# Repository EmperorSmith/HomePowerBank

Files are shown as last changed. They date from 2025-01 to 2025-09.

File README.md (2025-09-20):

# HomePowerBank

This project is a combined hardware-software effort around designing a control / management system for a home power bank. Unlike commercial USB power banks, this one is intended to serve as a sort of "generator substitute," having a stack of batteries large enough to supply an inverter during situations that otherwise lack power (general outage, off-grid living, etc).

# Design Goals

## Primary Goals

- Monitor a multi-cell battery stack
    - Measure cell voltage
    - Measure stack voltage
    - Measure stack current
    - Measure temperatures
    - Estimate cell state-of-charge
- Report monitored state to user
- Accept and react to user input for basic operations
- Protect pack against fault conditions
    - Overvoltage / Overcharge
    - Undervoltage / Undercharge
    - Overcurrent
    - Overtemperature
- Integrate control of external charger and inverter
    - Connect & disconnect battery stack bus and external devices
    - Produce on/off control output to charger
    - Take in fault input from charger
    - Produce on/off control output to inverter
    - Take in fault input from inverter

## Secondary Goals

- Provide bidirectional USB-C charging port
    - Supply external loads with 5V 1.5A power
    - Trickle-charge bank from external supply
- Take control commands from external communication interface
- Implement advanced diagnostics
- Implement flexible / extensible stack architecture
    - Adapt to different cell and IC counts
    - Adapt to different cell chemistries

# Tools

As much as possible, the tools used to produce the design should be freely available.

- Circuit schematic and layout creation will take place in [KiCAD](www.kicad.org)
- Block diagrams and similar drawing should use [draw.io](www.diagrams.net)
- Circuit simulations should be conducted in a free SPICE tool, like [ngspice](https://ngspice.sourceforge.io/) or [LTSpice](https://www.analog.com/en/resources/design-tools-and-calculators/ltspice-simulator.html)
- Documentation should be created using the Markdown language / format

# Philosophy

## System Design

When in doubt, design should err on the side of over-engineering, especially for the prototype phase.

## Project Code of Conduct

"Be excellent to each other" *- Bill S. Preston, Esq.*

## Usability

The system in basic form should be fully usable from the standpoint of a non-engineer, but should also offer the capabilities for a knowledgeable person to modify / alter the system to their desires.

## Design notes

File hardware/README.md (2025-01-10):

# System Blocks

## Internal Power Supply

### Description

This system will take the battery bank voltage and convert it to 5V to supply various aspects of the system (microcontroller, USB port, maybe even the BMS chips).

With the battery bank currently targeted at a 16S LFP configuration, this limits the maximum voltage to about 55V. Conventional buck regulators should be able to convert at this ratio and voltage range. It is also permissible to use a flyback regulator, although this will present additional challenges over a buck regulator.

If other system rails are needed, secondary voltage regulators will be added.

There will be a secondary LV battery backup system to ensure that faults with the main bank will not cause immediate shutdown of the system. This is to ensure good shutdown and startup behavior and preserve information about the system.

### Requirements

- Input Voltage : 32V to 56V
- Input Current : (as needed)
- Output Voltage : 5V +/- 0.2V
- Output Current : at least 1.5A, no more than 3A

## Trickle Charge Circuit

### Description

This system will take in 5V from the USB port and boost it up to about 55V to trickle-charge the battery bank.

The power conversion topology chosen is a flyback converter. The step-up ratio is just too large to use a conventional boost converter.

Ideally, the output of the buck regulator will have a constant-current-limiting circuit attached to it to accommodate a wide range of battery bank voltages.

### Requirements

- Input Voltage : 5.0V +/- 0.25V
- Input Current : no more than 1A average
- Output Voltage : 53V +/- 2V
- Output Current : no more than 50mA

## USB Interface

### Description

A USB C socket will be present on the unit. It will be capable of both supplying power to an external load and drawing power from an external source.

### Requirements

Despite having a USB C connector, the port will not have full USB 3 communication capabilities. If communication is added, it will be USB 2.x compliant only.

While the port will be able to both source and sink power, USB PD communication will not be implemented. Instead, a user-activated switch will determine the direction of the power flow. On switch toggle, the USB port will fully disconnect, then reconfigure the CC pins as necessary and monitor for connection.

When sourcing power, the interface will use CC pin resistor strapping to communicate the availability of up to 1.5A of current at 5.0V to downstream devices.

When sinking power, the interface will measure the CC pin voltage and respect the current limits communicated in that manner. The trickle charge circuit will not activate unless at least 1.5A of current is available from the upstream device.

The USB port will include a power switch and current sense amplifier to monitor operation. Fault conditions will trigger a port shutdown. Reconnection will be attempted after a timeout.

## Microcontroller

### Description

A local microcontroller will handle all operation and monitoring of the battery bank and attached systems (charger, inverter, USB-attached device). It will interface with users only in the most basic of manners (buttons / switches / LED indicators). More complex interactions will require an external device, to which the microcontroller will provide information for futher processing and display. The microcontroller will retain key state information across power cycles.

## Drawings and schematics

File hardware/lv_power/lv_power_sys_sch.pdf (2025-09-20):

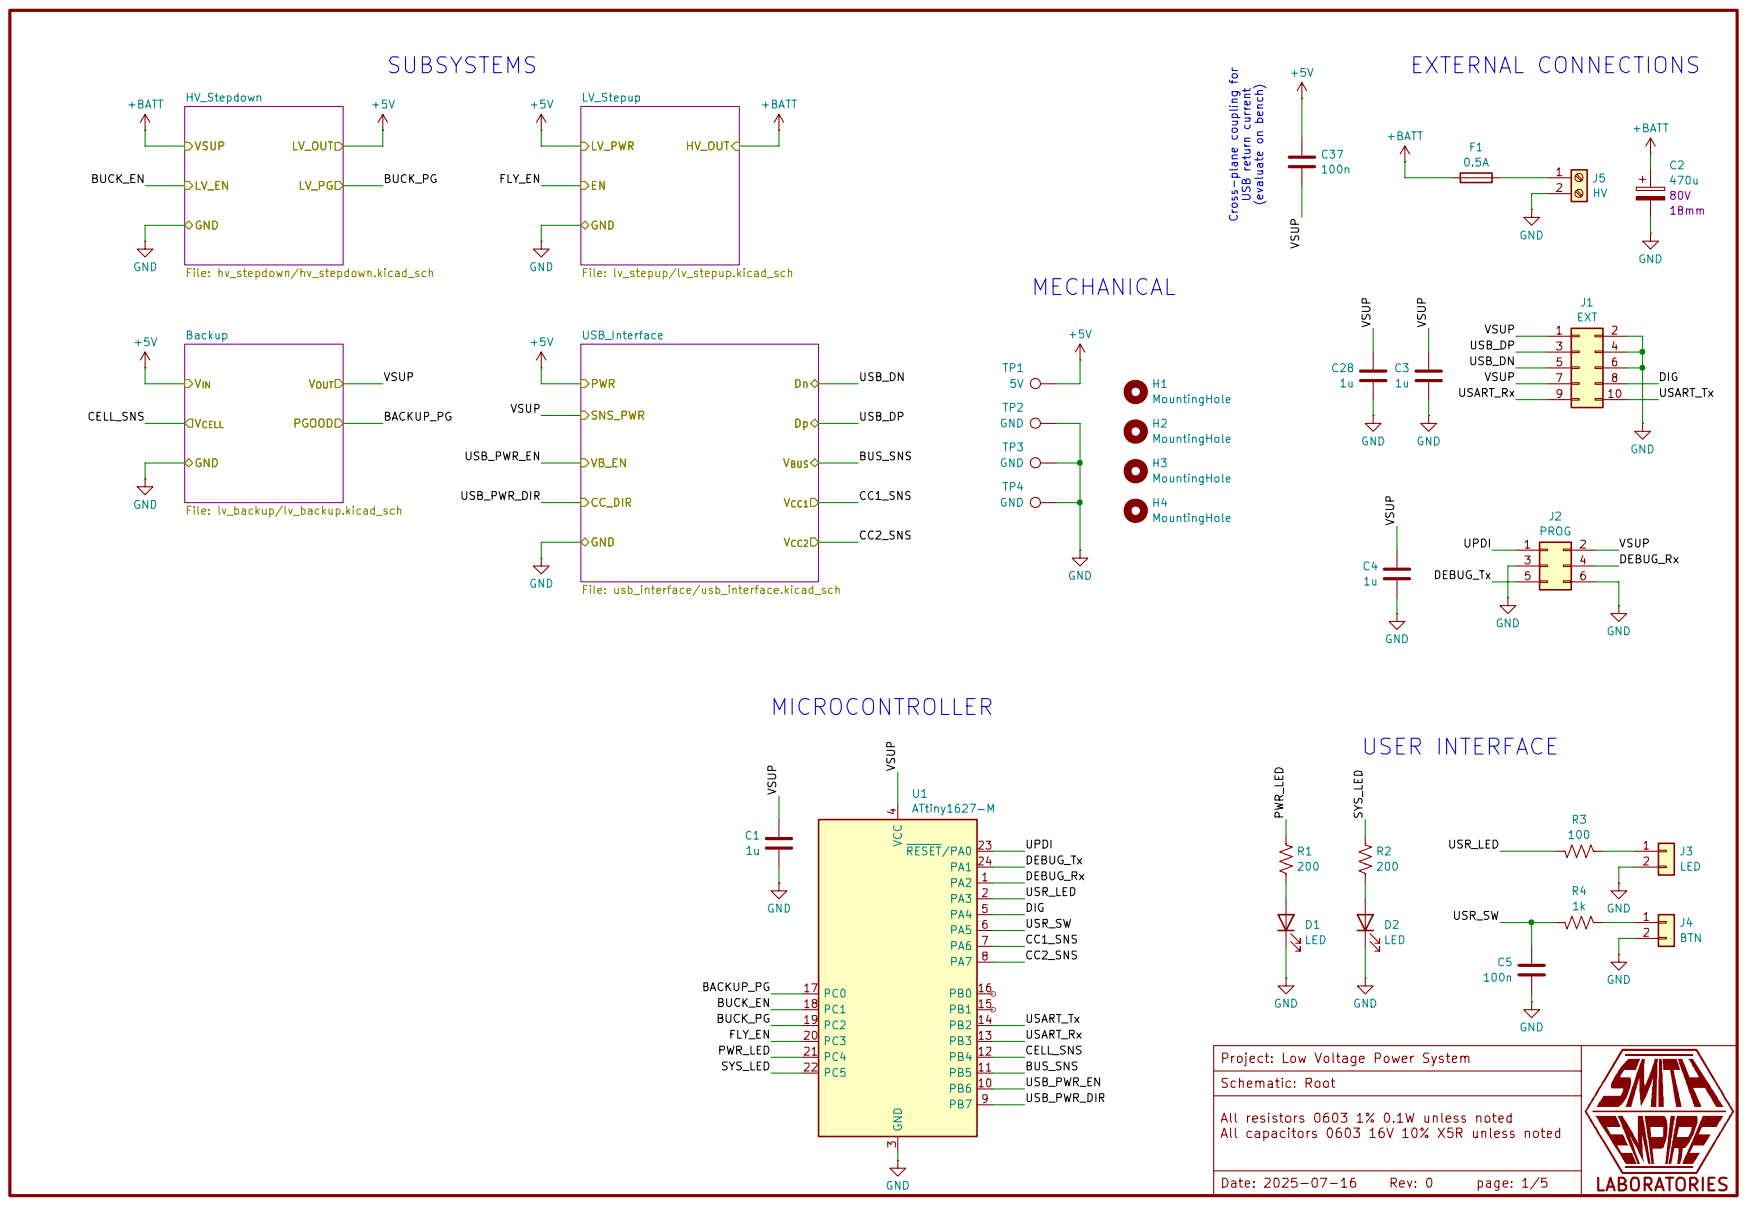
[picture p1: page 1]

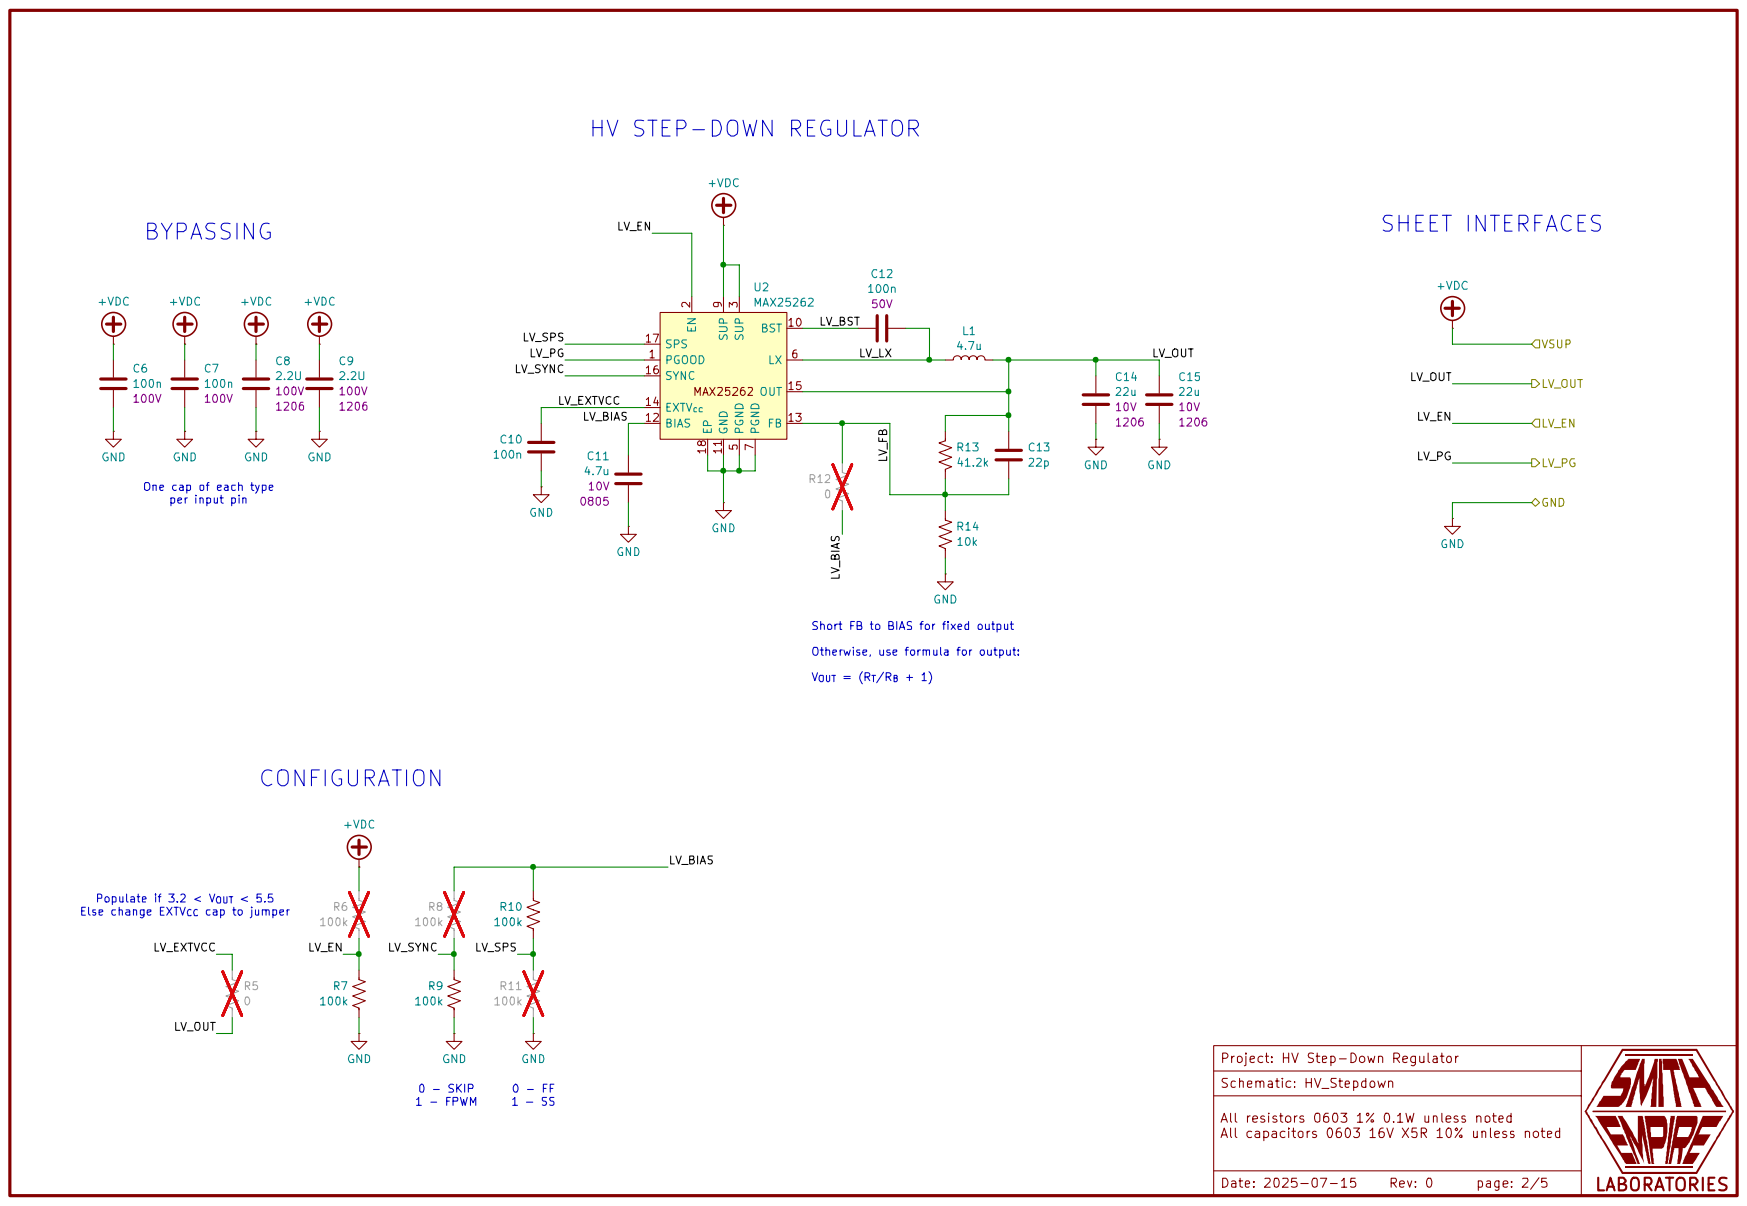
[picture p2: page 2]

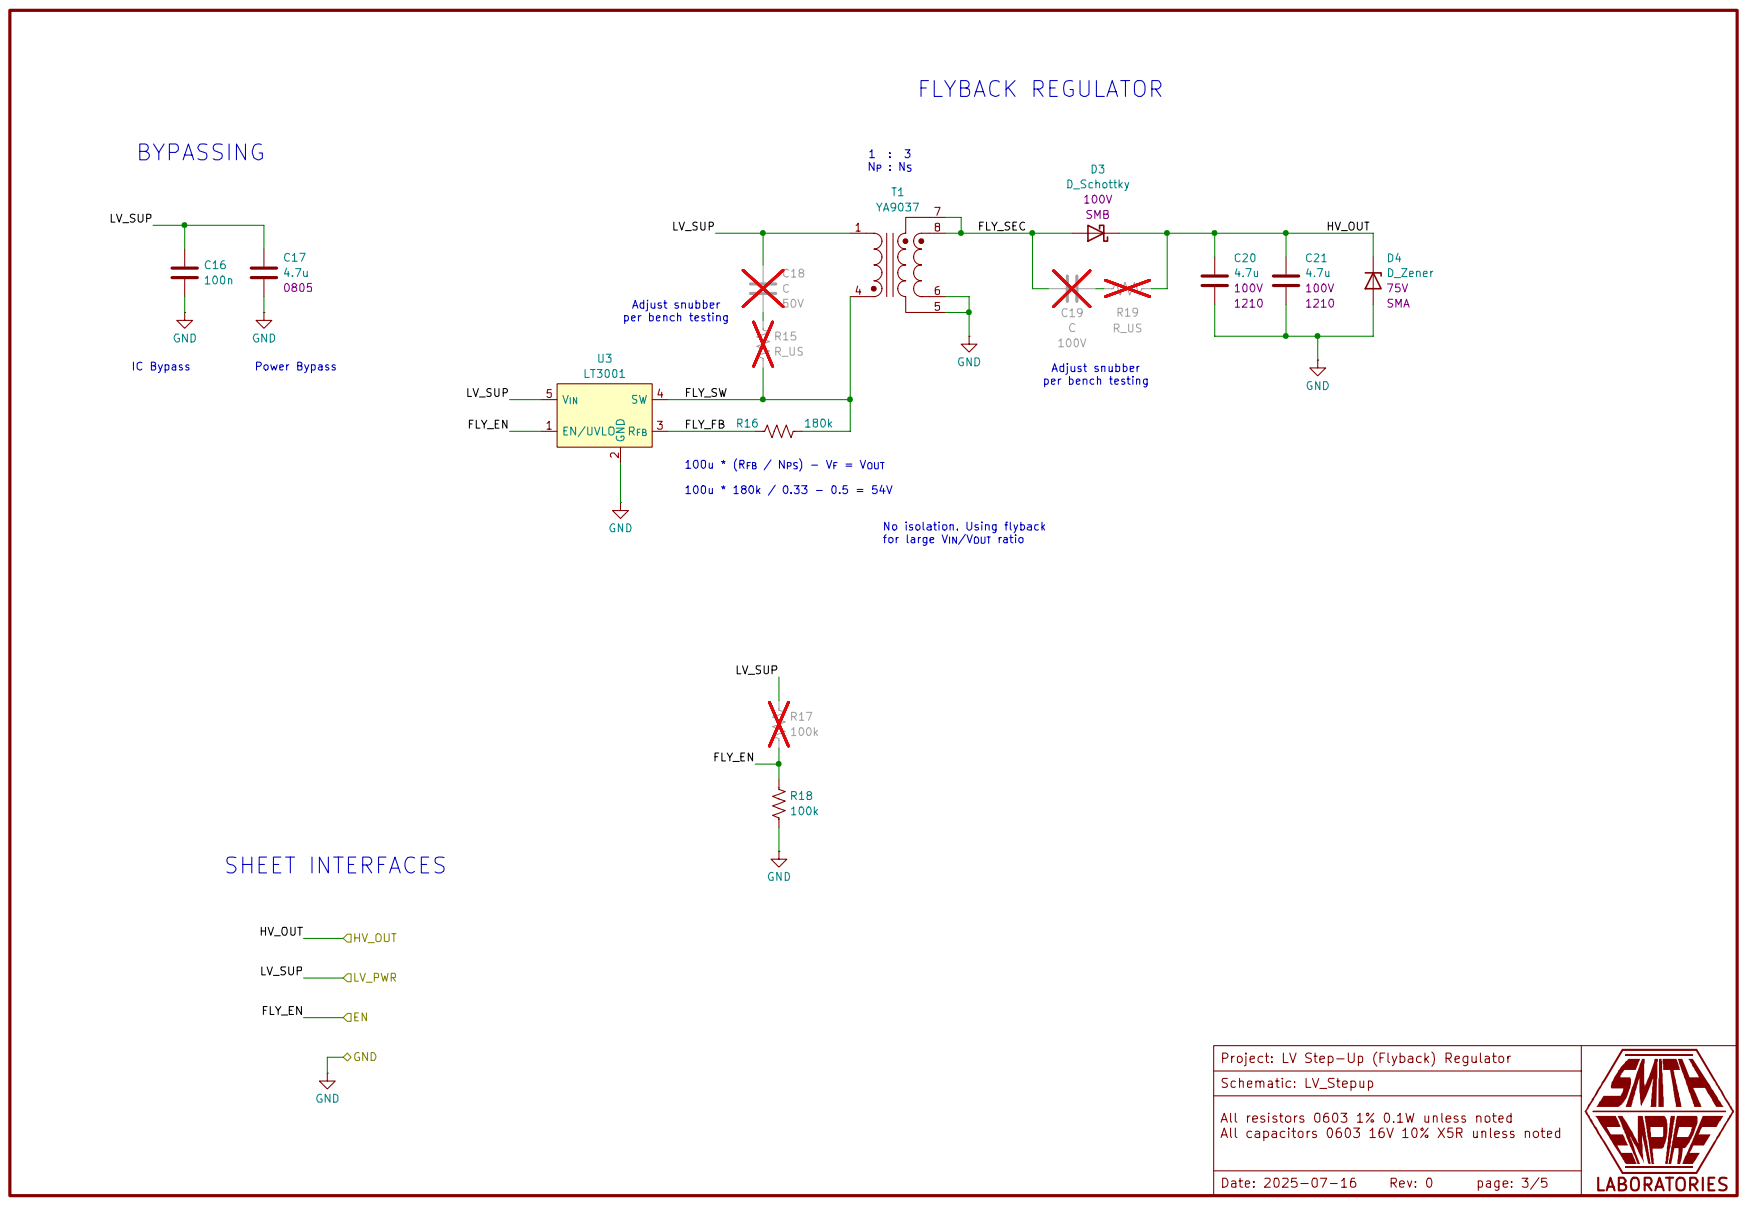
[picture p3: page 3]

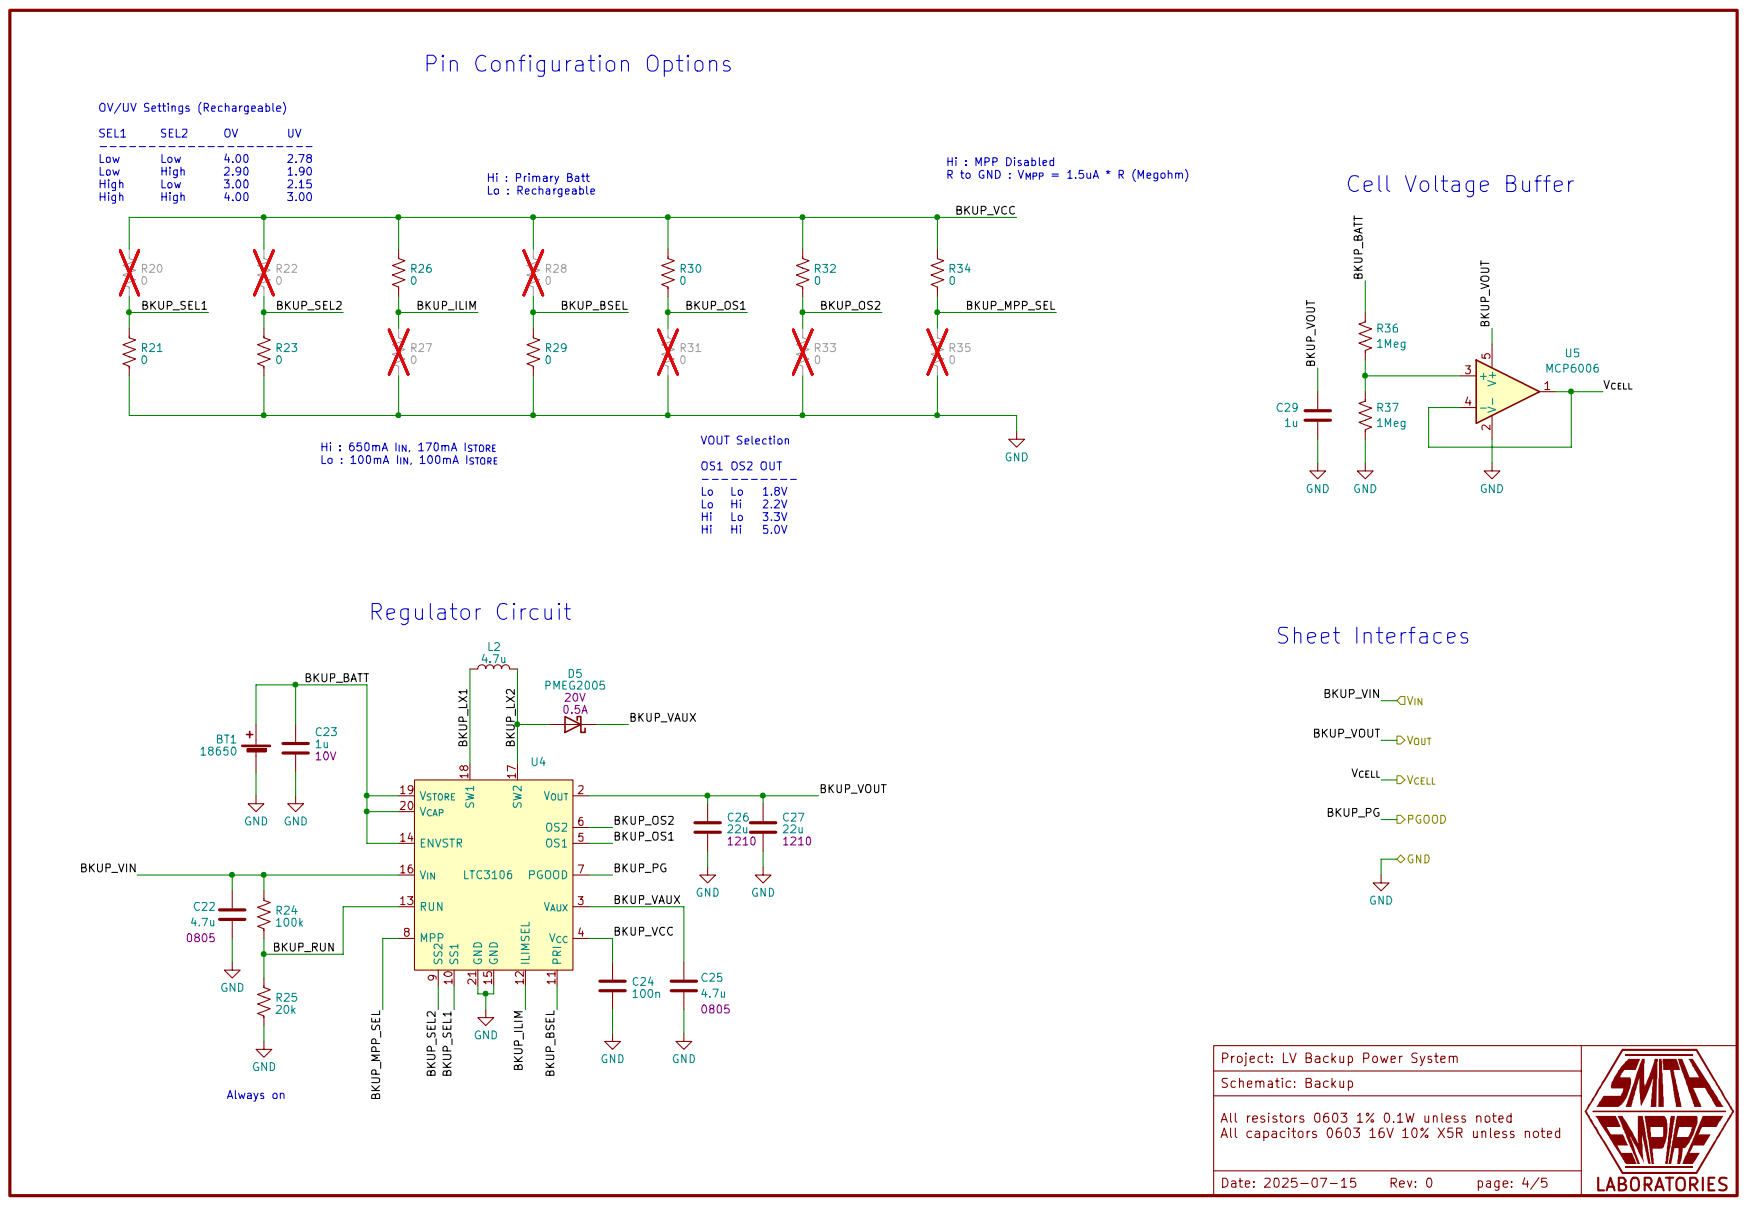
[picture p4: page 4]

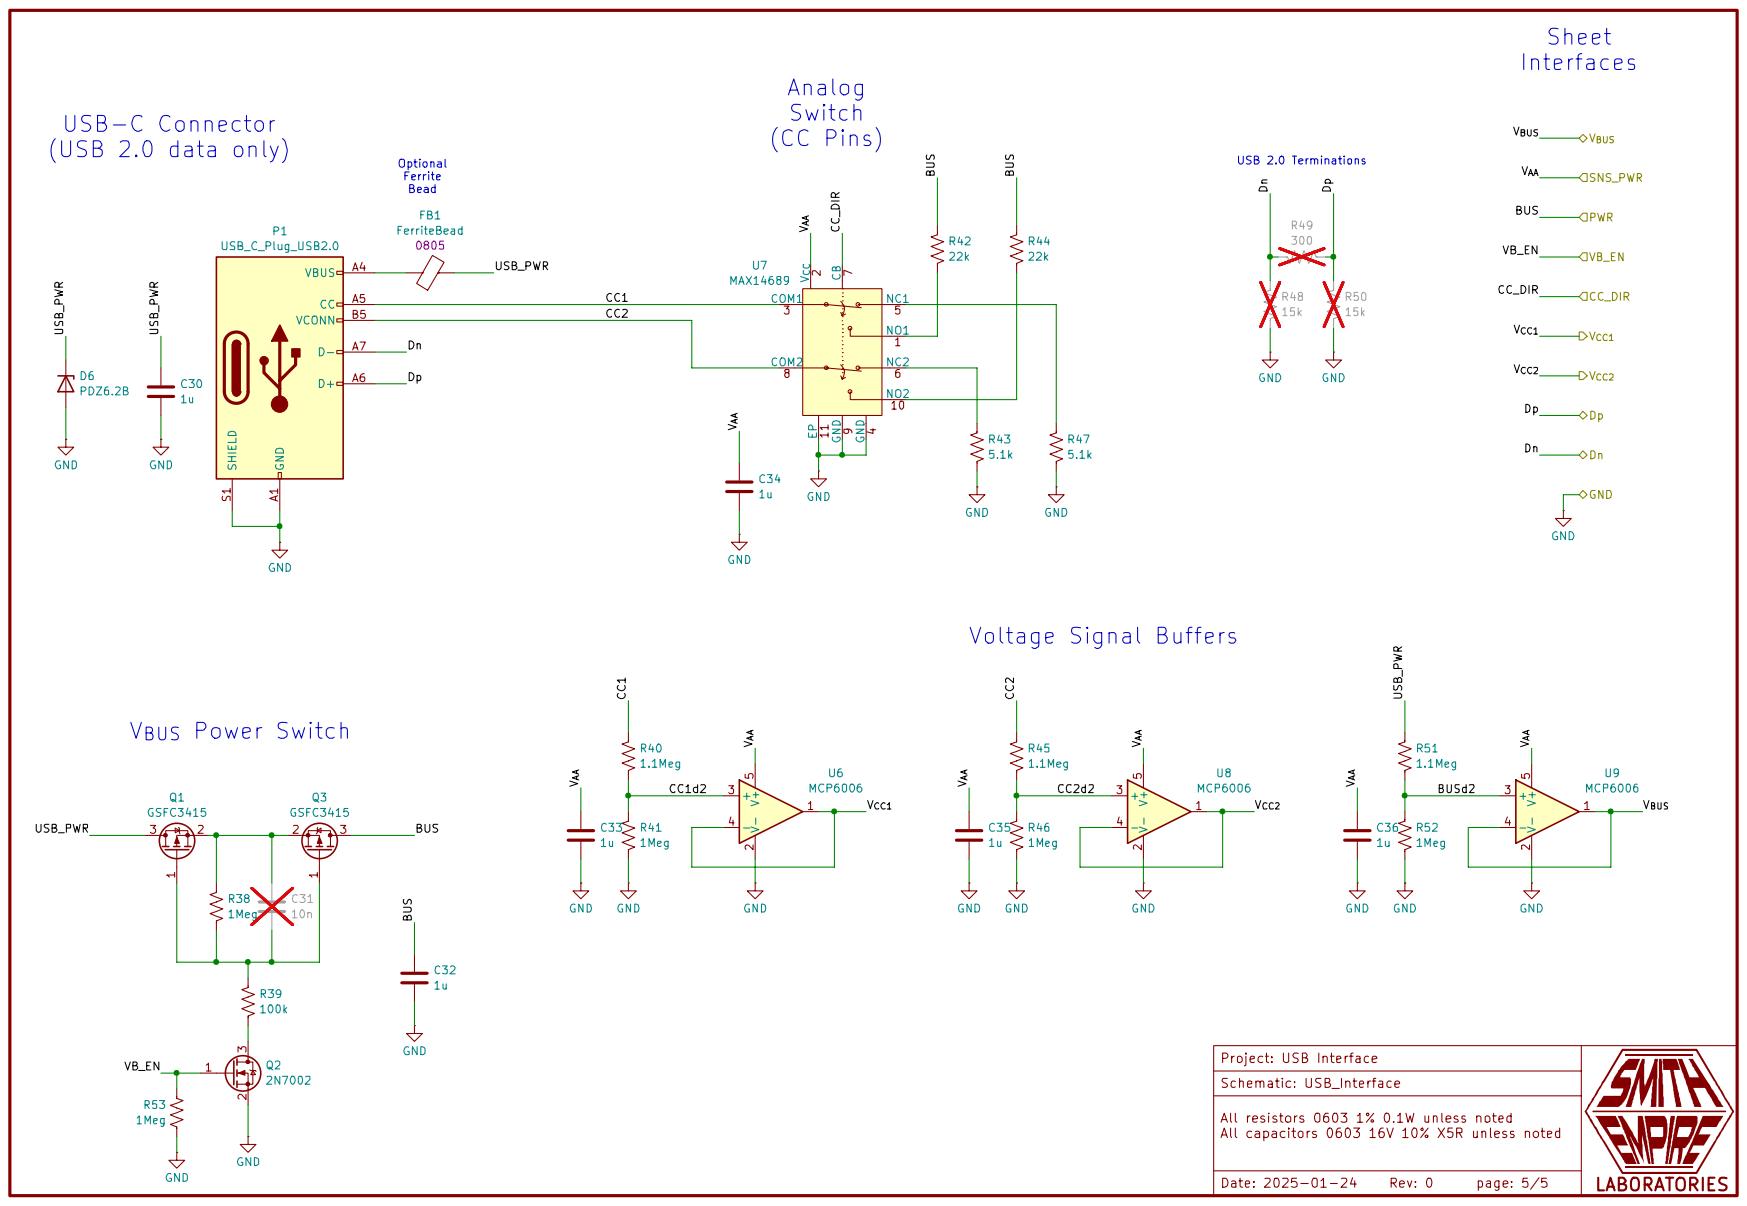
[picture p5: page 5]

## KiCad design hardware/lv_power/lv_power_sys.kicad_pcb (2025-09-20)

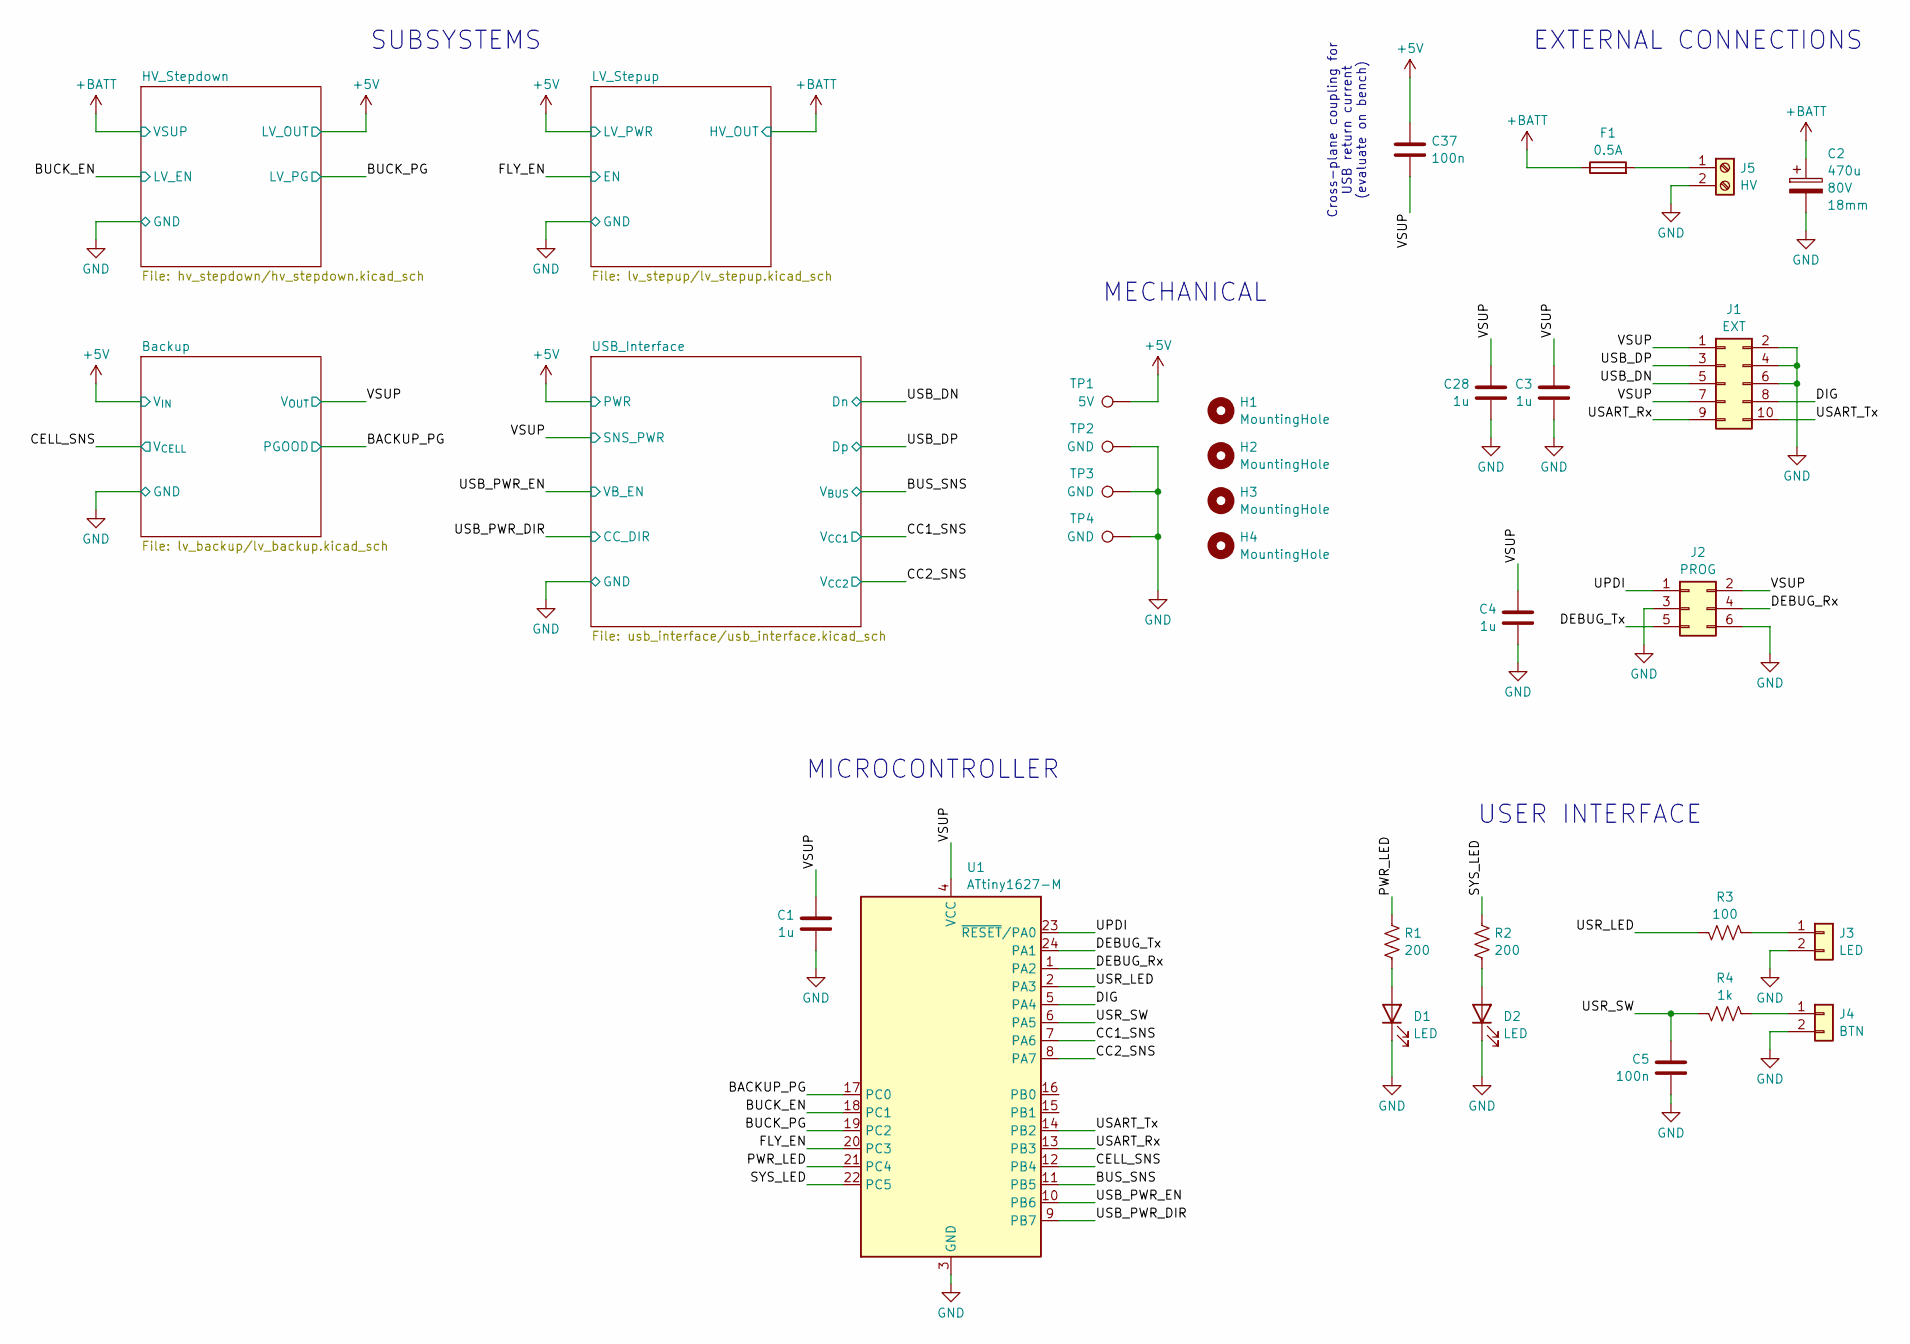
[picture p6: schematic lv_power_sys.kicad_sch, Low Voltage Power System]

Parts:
C1, C3, C4, C28: 1u; C_0603_1608Metric
C2: 470u; CP_Elec_18x17.5
C5, C37: 100n; C_0603_1608Metric
D1, D2: LED; D_0603_1608Metric
F1: 0.5A; Fuseholder_Clip-5x20mm_Keystone_3512_Inline_P23.62x7.27mm_D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
H1, H2, H3, H4: MountingHole; MountingHole_3.2mm_M3
J1: EXT; IDC-Header_2x05_P2.54mm_Vertical
J2: PROG; PinHeader_2x03_P2.54mm_Vertical
J3: LED; PinHeader_1x02_P2.54mm_Vertical
J4: BTN; PinHeader_1x02_P2.54mm_Vertical
J5: HV; SolderWire-0.15sqmm_1x02_P4mm_D0.5mm_OD1.5mm
R1, R2: 200; R_0603_1608Metric
R3: 100; R_0603_1608Metric
R4: 1k; R_0603_1608Metric
TP1: 5V; TestPoint_Pad_D1.5mm
TP2, TP3, TP4: GND; TestPoint_Pad_D1.5mm
U1: ATtiny1627-M; QFN-24-1EP_4x4mm_P0.5mm_EP2.6x2.6mm

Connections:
+5V: C37.1, TP1.1; also elsewhere on the board
+BATT: C2.1, F1.1; also elsewhere on the board
/BACKUP_PG: U1.17 (PC0); also elsewhere on the board
/BUCK_EN: U1.18 (PC1); also elsewhere on the board
/BUCK_PG: U1.19 (PC2); also elsewhere on the board
/BUS_SNS: U1.11 (PB5); also elsewhere on the board
/CC1_SNS: U1.7 (PA6); also elsewhere on the board
/CC2_SNS: U1.8 (PA7); also elsewhere on the board
/CELL_SNS: U1.12 (PB4); also elsewhere on the board
/DEBUG_Rx: J2.4, U1.1 (PA2)
/DEBUG_Tx: J2.5, U1.24 (PA1)
/DIG: J1.8, U1.5 (PA4)
/FLY_EN: U1.20 (PC3); also elsewhere on the board
/LED0: R1.2, U1.21 (PC4)
/LED1: R2.2, U1.22 (PC5)
/UPDI: J2.1, U1.23 (~RESET/PA0)
/USART_Rx: J1.9, U1.13 (PB3)
/USART_Tx: J1.10, U1.14 (PB2)
/USB_DN: J1.5; also elsewhere on the board
/USB_DP: J1.3; also elsewhere on the board
/USB_PWR_DIR: U1.9 (PB7); also elsewhere on the board
/USB_PWR_EN: U1.10 (PB6); also elsewhere on the board
/USR_LED: R3.1, U1.2 (PA3)
/USR_SW: C5.1, R4.1, U1.6 (PA5)
/VSUP: C1.1, C3.1, C4.1, C28.1, C37.2, J1.1, J1.7, J2.2, U1.4 (VCC); also elsewhere on the board
GND: C1.2, C2.2, C3.2, C4.2, C5.2, C28.2, D1.1 (K), D2.1 (K), J1.2, J1.4, J1.6, J2.3, J2.6, J3.2, J4.2, J5.2, TP2.1, TP3.1, TP4.1, U1.3 (GND), U1.25 (GND); also elsewhere on the board
unnamed: D1.2 (A), R1.1
unnamed: D2.2 (A), R2.1
unnamed: J3.1, R3.2
unnamed: J4.1, R4.2
unnamed: F1.2, J5.1

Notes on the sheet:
USER INTERFACE
SUBSYSTEMS
EXTERNAL CONNECTIONS
Cross-plane coupling for USB return current (evaluate on bench)
MECHANICAL
MICROCONTROLLER

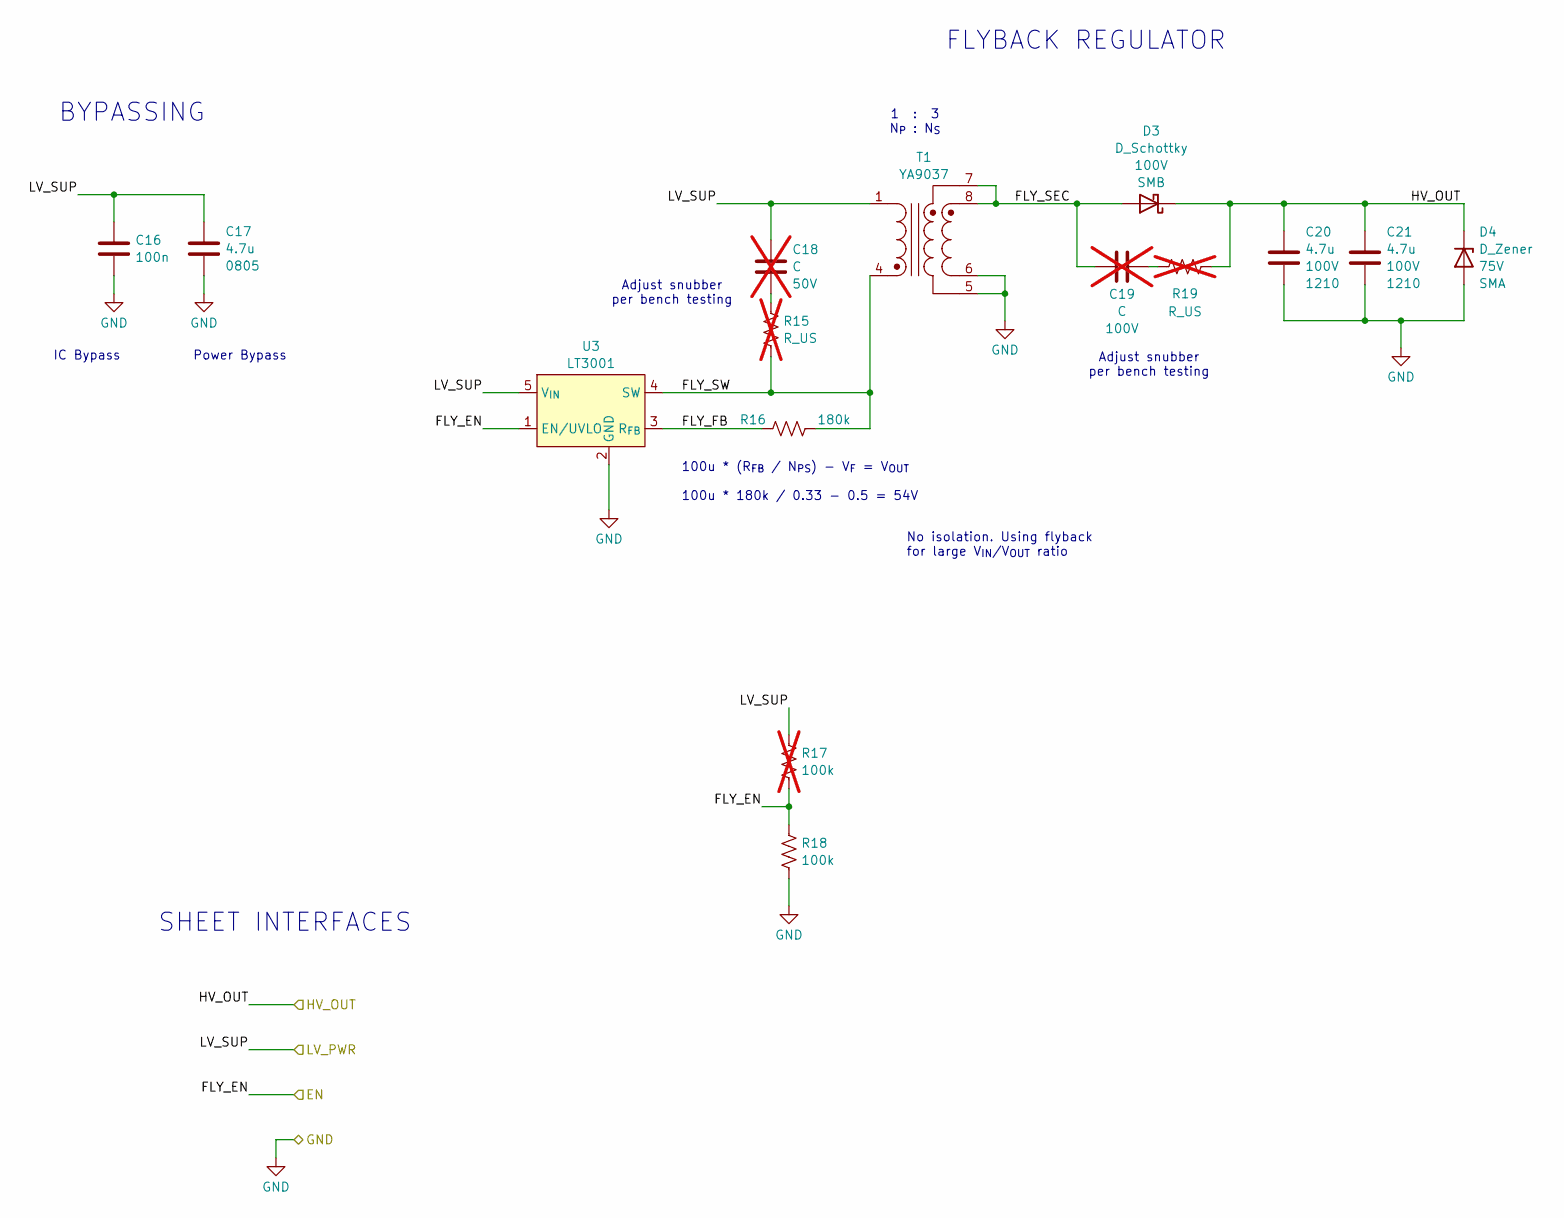
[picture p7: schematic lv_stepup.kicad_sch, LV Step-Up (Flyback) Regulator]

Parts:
C16: 100n; C_0603_1608Metric
C17: 4.7u; C_0805_2012Metric
C18, C19: C; C_0603_1608Metric; not fitted
C20, C21: 4.7u; C_1210_3225Metric
D3: D_Schottky; D_SMB
D4: D_Zener; D_SMA
R15, R19: R_US; R_0603_1608Metric; not fitted
R16: 180k; R_0603_1608Metric
R17: 100k; R_0603_1608Metric; not fitted
R18: 100k; R_0603_1608Metric
T1: YA9037; Coilcraft_YA903x
U3: LT3001; SOT-23-5

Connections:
+5V: C16.1, C17.1, C18.1, R17.2, T1.1, U3.5 (V_{IN}); also elsewhere on the board
+BATT: C20.1, C21.1, D3.1 (K), D4.1 (K), R19.2; also elsewhere on the board
/FLY_EN: R17.1, R18.2, U3.1 (EN/UVLO); also elsewhere on the board
/LV_Stepup/FLY_FB: R16.1, U3.3 (R_{FB})
/LV_Stepup/FLY_SEC: C19.1, D3.2 (A), T1.7, T1.8
/LV_Stepup/FLY_SW: R15.1, R16.2, T1.4, U3.4 (SW)
GND: C16.2, C17.2, C20.2, C21.2, D4.2 (A), R18.1, T1.5, T1.6, U3.2 (GND); also elsewhere on the board
unnamed: C18.2, R15.2
unnamed: C19.2, R19.1

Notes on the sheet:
No isolation. Using flyback for large V_{IN}/V_{OUT} ratio
IC Bypass
1 : 3 N_{P} : N_{S}
FLYBACK REGULATOR
100u * (R_{FB} / N_{PS}) - V_{F} = V_{OUT} 100u * 180k / 0.33 - 0.5 = 54V
SHEET INTERFACES
Adjust snubber per bench testing
Power Bypass
BYPASSING

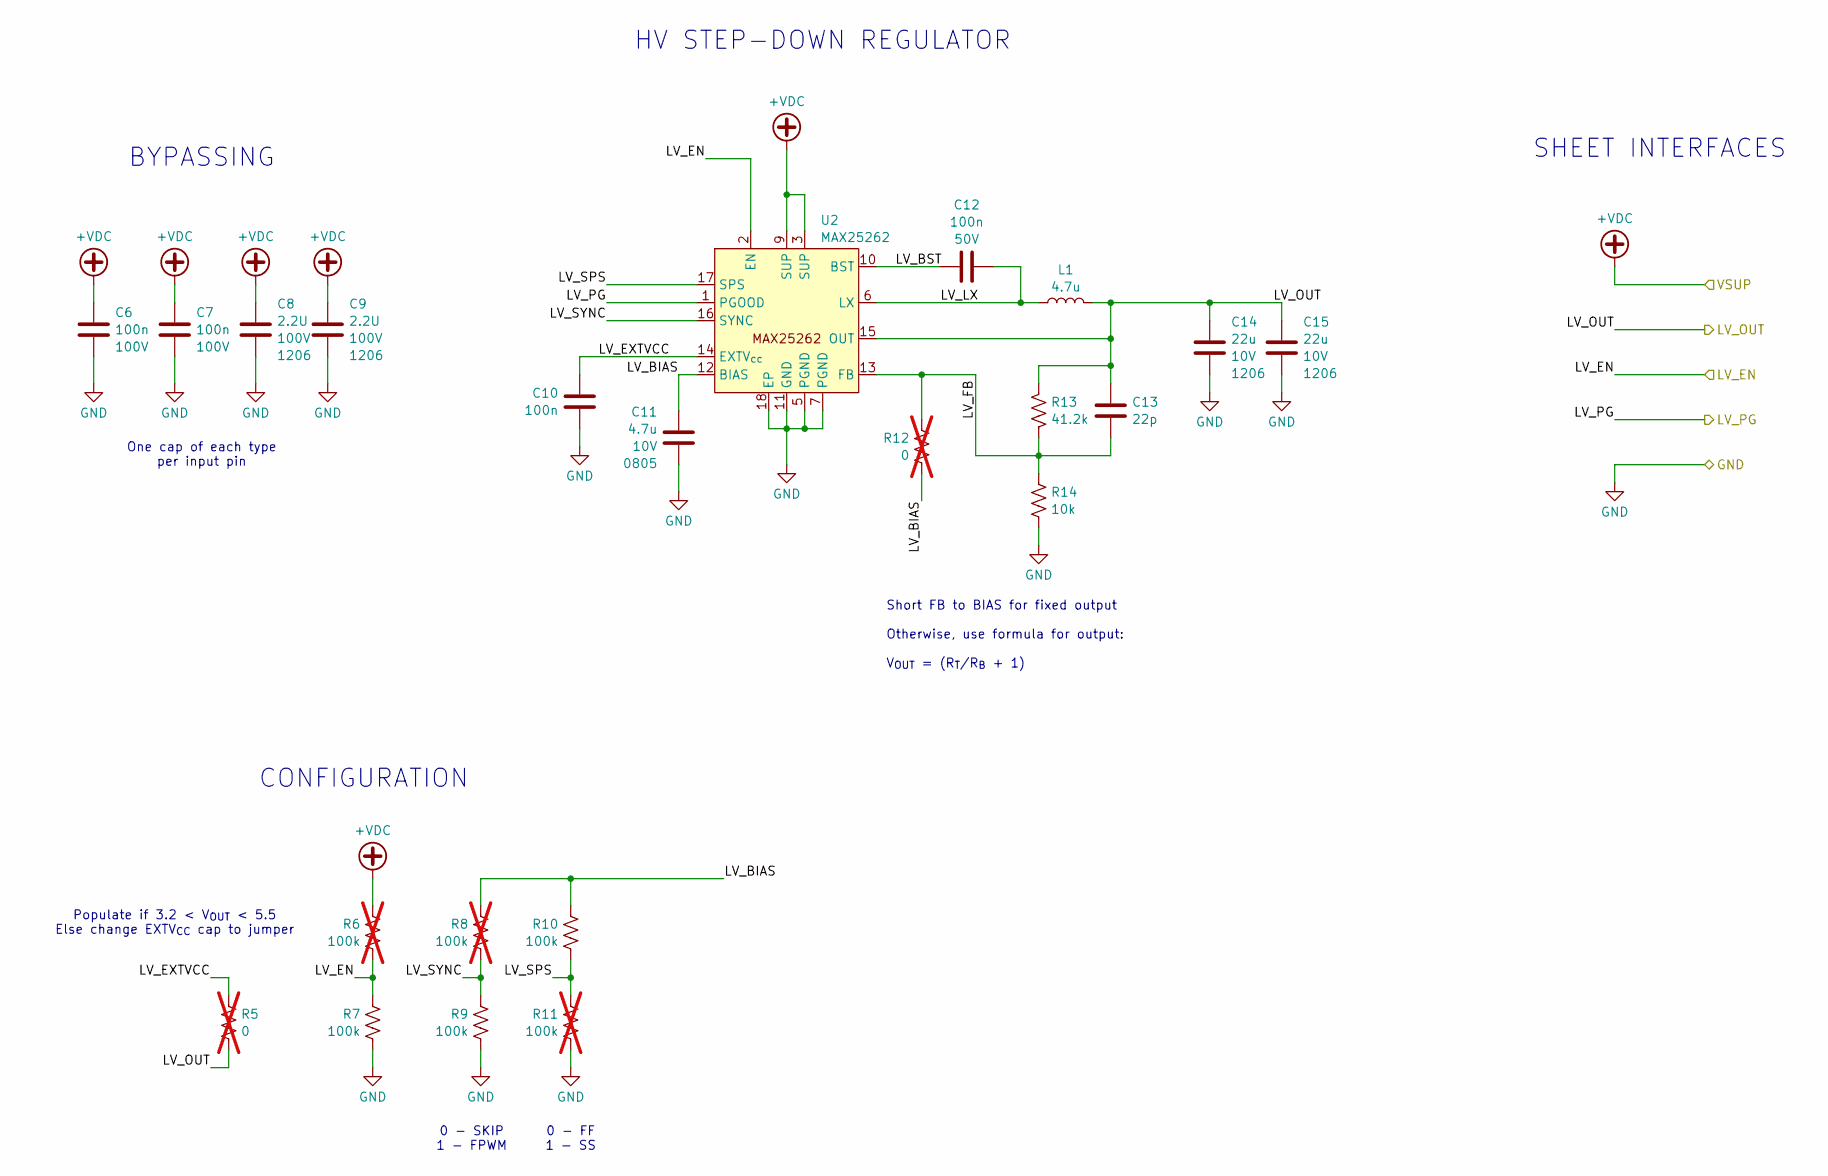
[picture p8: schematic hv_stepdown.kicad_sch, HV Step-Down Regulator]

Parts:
C6, C7, C10, C12: 100n; C_0603_1608Metric
C8, C9: 2.2U; C_1210_3225Metric
C11: 4.7u; C_0805_2012Metric
C13: 22p; C_0603_1608Metric
C14, C15: 22u; C_1210_3225Metric
L1: 4.7u; L_Coilcraft_XAL6060-XXX
R5, R12: 0; R_0603_1608Metric; not fitted
R6, R8, R11: 100k; R_0603_1608Metric; not fitted
R7, R9, R10: 100k; R_0603_1608Metric
R13: 41.2k; R_0603_1608Metric
R14: 10k; R_0603_1608Metric
U2: MAX25262; ADI_21-100429

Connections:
+5V: C13.2, C14.2, C15.2, L1.2, R5.1, R13.2, U2.15 (OUT); also elsewhere on the board
+BATT: C6.1, C7.1, C8.1, C9.1, R6.1, U2.3 (SUP), U2.9 (SUP); also elsewhere on the board
/BUCK_EN: R6.2, R7.1, U2.2 (EN); also elsewhere on the board
/BUCK_PG: U2.1 (PGOOD); also elsewhere on the board
/HV_Stepdown/LV_BIAS: C11.2, R8.1, R10.1, R12.2, U2.12 (BIAS)
/HV_Stepdown/LV_BST: C12.1, U2.10 (BST)
/HV_Stepdown/LV_EXTVCC: C10.1, R5.2, U2.14 (EXTV_{cc})
/HV_Stepdown/LV_FB: C13.1, R12.1, R13.1, R14.2, U2.13 (FB)
/HV_Stepdown/LV_LX: C12.2, L1.1, U2.6 (LX)
/HV_Stepdown/LV_SPS: R10.2, R11.1, U2.17 (SPS)
/HV_Stepdown/LV_SYNC: R8.2, R9.1, U2.16 (SYNC)
GND: C6.2, C7.2, C8.2, C9.2, C10.2, C11.1, C14.1, C15.1, R7.2, R9.2, R11.2, R14.1, U2.5 (PGND), U2.7 (PGND), U2.11 (GND), U2.18 (EP); also elsewhere on the board

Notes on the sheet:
HV STEP-DOWN REGULATOR
0 - SKIP 1 - FPWM
Populate if 3.2 < V_{OUT} < 5.5 Else change EXTV_{CC} cap to jumper
0 - FF 1 - SS
SHEET INTERFACES
Short FB to BIAS for fixed output Otherwise, use formula for output: V_{OUT} = (R_{T}/R_{B} + 1)
CONFIGURATION
BYPASSING
One cap of each type per input pin

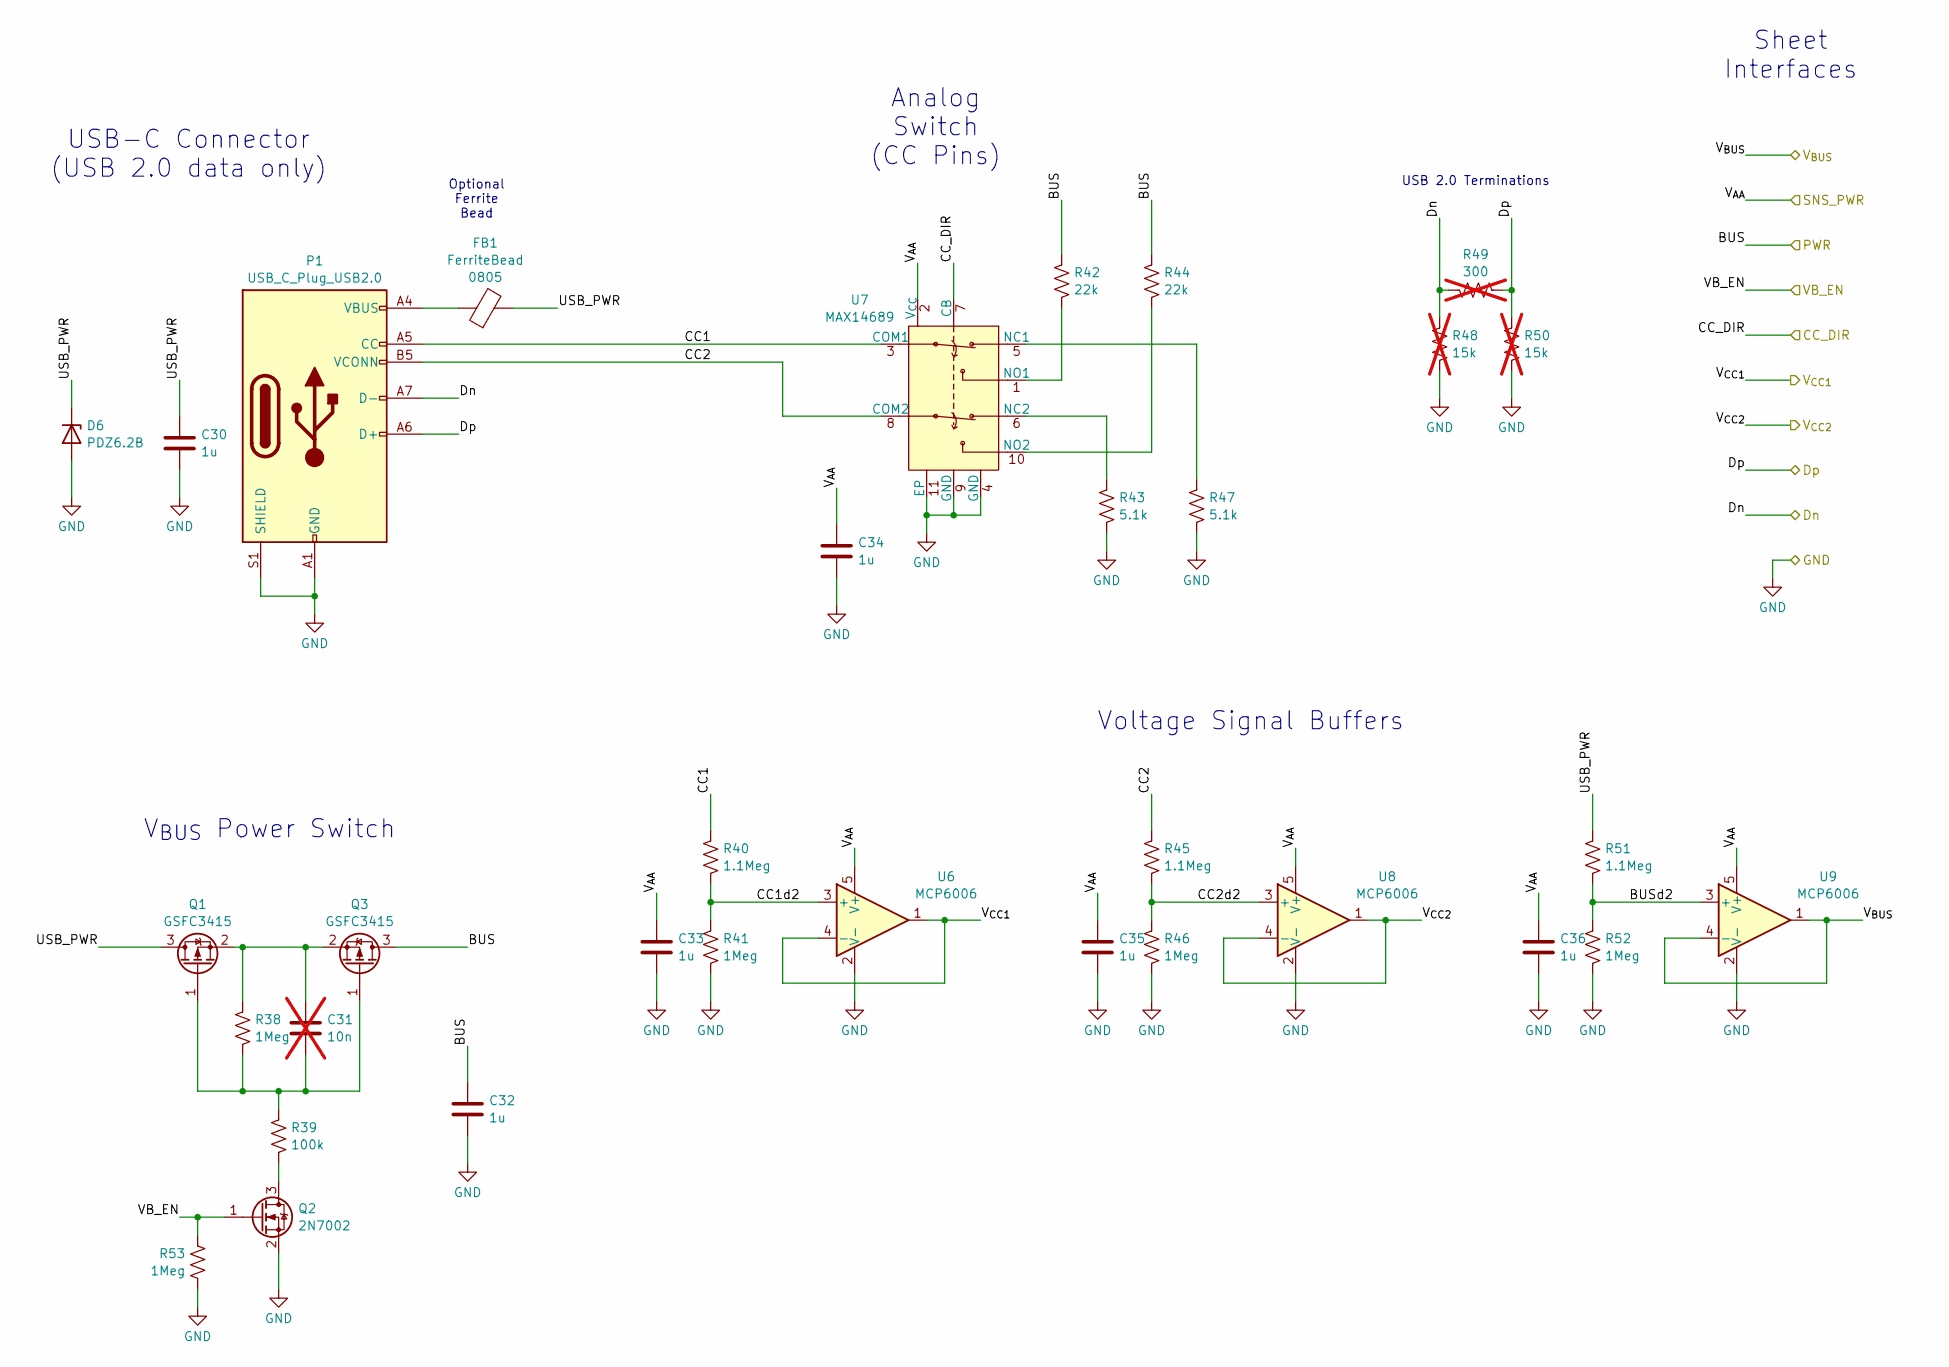
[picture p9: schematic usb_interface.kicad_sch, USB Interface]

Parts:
C30, C32, C33, C34, C35, C36: 1u; C_0603_1608Metric_Pad1.08x0.95mm_HandSolder
C31: 10n; C_0603_1608Metric; not fitted
D6: PDZ6.2B; D_SOD-123
FB1: FerriteBead; L_0805_2012Metric
P1: USB_C_Plug_USB2.0; USB_C_Receptacle_GCT_USB4085
Q1, Q3: GSFC3415; SOT-23
Q2: 2N7002; SOT-23
R38, R41, R46, R52, R53: 1Meg; R_0603_1608Metric
R39: 100k; R_0603_1608Metric
R40, R45, R51: 1.1Meg; R_0603_1608Metric
R42, R44: 22k; R_0603_1608Metric
R43, R47: 5.1k; R_0603_1608Metric
R48, R50: 15k; R_0603_1608Metric; not fitted
R49: 300; R_0603_1608Metric; not fitted
U6, U8, U9: MCP6006; TSOT-23-5
U7: MAX14689; ADI_21-100013A

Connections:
+5V: C32.1, Q3.3 (D), R42.1, R44.1; also elsewhere on the board
/BUS_SNS: U9.1, U9.4 (-); also elsewhere on the board
/CC1_SNS: U6.1, U6.4 (-); also elsewhere on the board
/CC2_SNS: U8.1, U8.4 (-); also elsewhere on the board
/USB_DN: P1.A7 (D-), R48.1, R49.1; also elsewhere on the board
/USB_DP: P1.A6 (D+), R49.2, R50.1; also elsewhere on the board
/USB_Interface/BUSd2: R51.2, R52.1, U9.3 (+)
/USB_Interface/CC1: P1.A5 (CC), R40.1, U7.3 (COM1)
/USB_Interface/CC1d2: R40.2, R41.1, U6.3 (+)
/USB_Interface/CC2: P1.B5 (VCONN), R45.1, U7.8 (COM2)
/USB_Interface/CC2d2: R45.2, R46.1, U8.3 (+)
/USB_Interface/USB_PWR: C30.1, D6.1 (K), FB1.2, Q1.3 (D), R51.1
/USB_PWR_DIR: U7.7 (CB); also elsewhere on the board
/USB_PWR_EN: Q2.1 (G), R53.1; also elsewhere on the board
/VSUP: C33.1, C34.1, C35.1, C36.1, U6.5 (V+), U7.2 (V_{CC}), U8.5 (V+), U9.5 (V+); also elsewhere on the board
GND: C30.2, C32.2, C33.2, C34.2, C35.2, C36.2, D6.2 (A), P1.A1 (GND), P1.A12 (GND), P1.B1 (GND), P1.B12 (GND), P1.S1 (SHIELD), Q2.2 (S), R41.2, R43.2, R46.2, R47.2, R48.2, R50.2, R52.2, R53.2, U6.2 (V-), U7.4 (GND), U7.9 (GND), U7.11 (EP), U8.2 (V-), U9.2 (V-); also elsewhere on the board
unnamed: FB1.1, P1.A4 (VBUS), P1.A9 (VBUS), P1.B4 (VBUS), P1.B9 (VBUS)
unnamed: C31.2, Q1.1 (G), Q3.1 (G), R38.2, R39.1
unnamed: C31.1, Q1.2 (S), Q3.2 (S), R38.1
unnamed: Q2.3 (D), R39.2
unnamed: R47.1, U7.5 (NC1)
unnamed: R43.1, U7.6 (NC2)
unnamed: R42.2, U7.1 (NO1)
unnamed: R44.2, U7.10 (NO2)

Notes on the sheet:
Sheet Interfaces
V_{BUS} Power Switch
Analog Switch (CC Pins)
Optional Ferrite Bead
Voltage Signal Buffers
USB-C Connector (USB 2.0 data only)
USB 2.0 Terminations

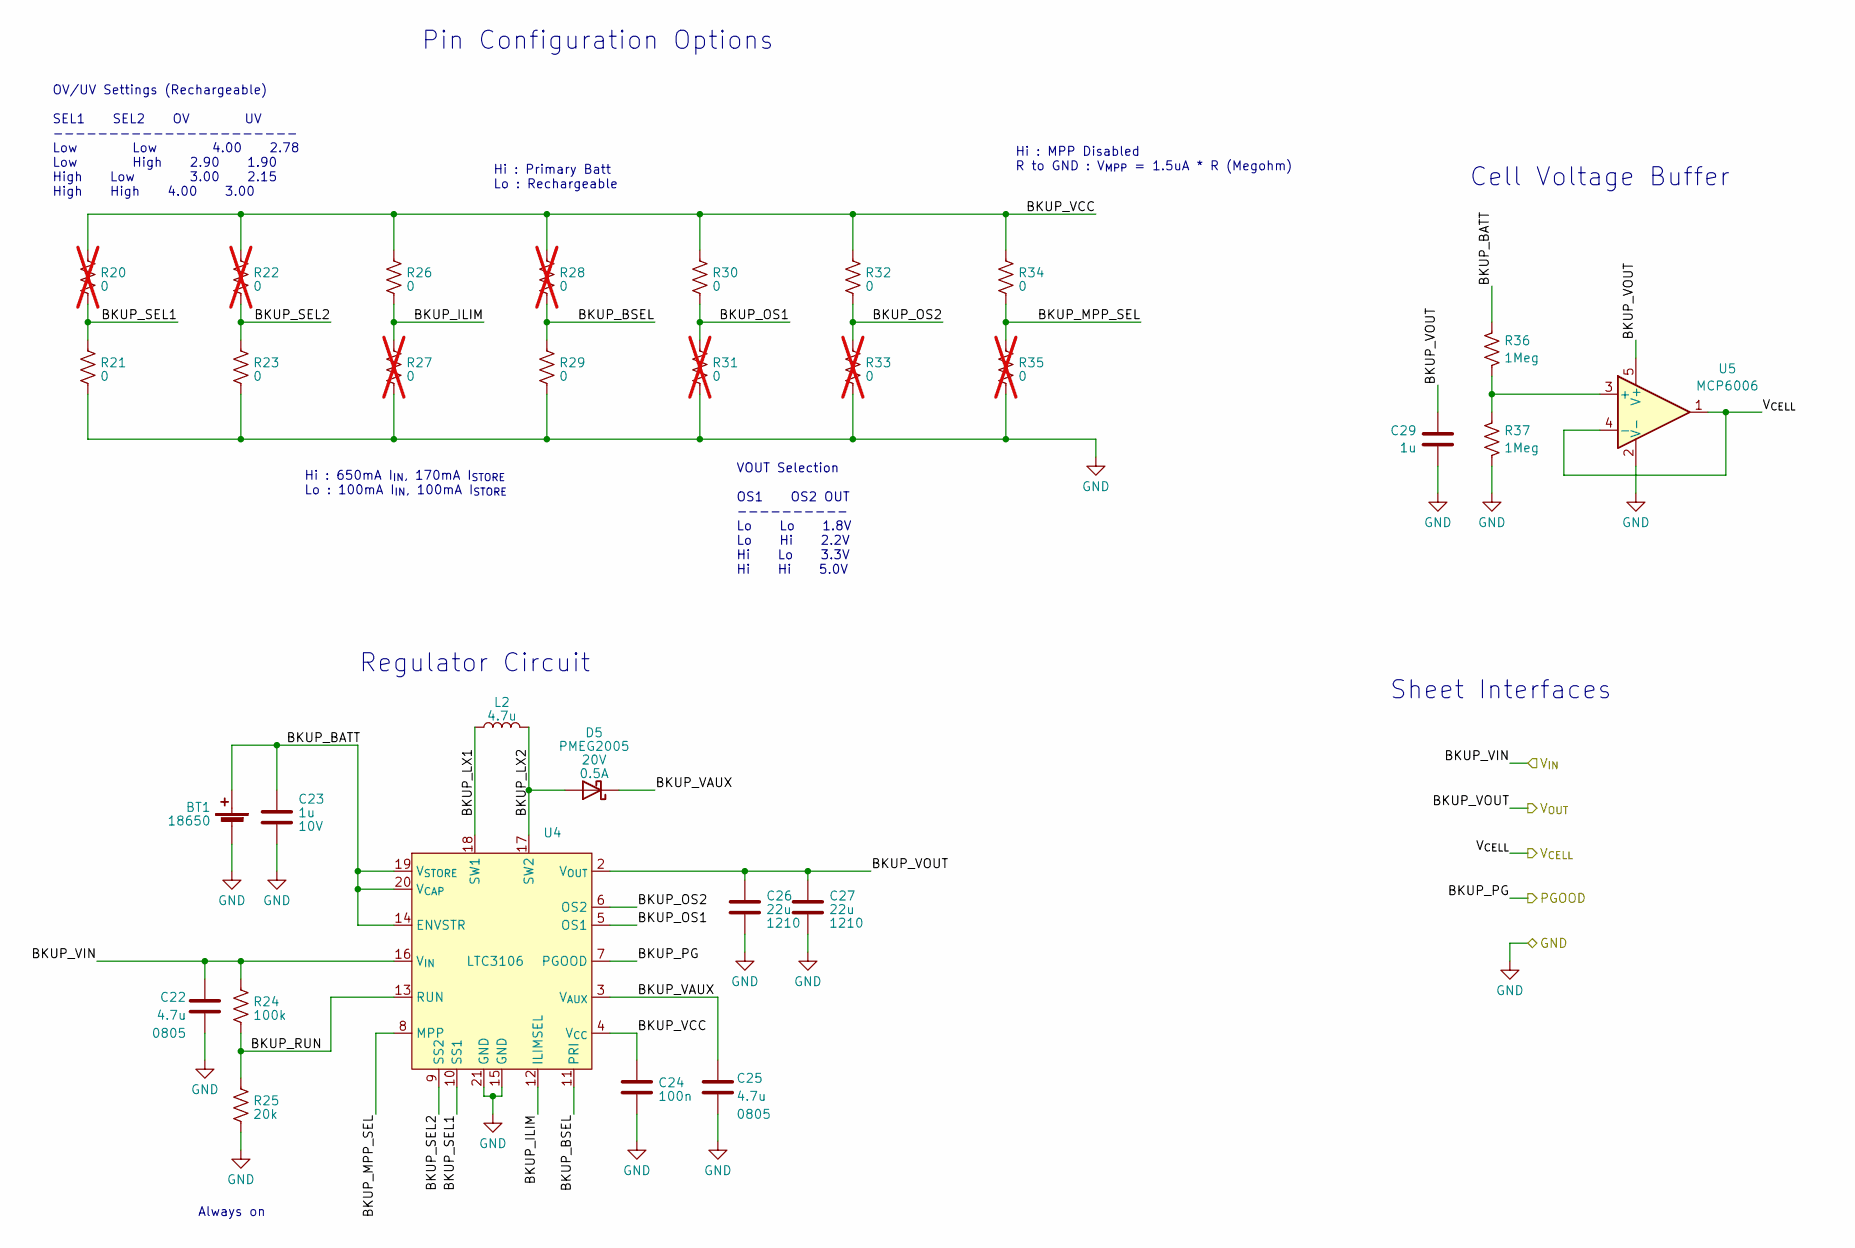
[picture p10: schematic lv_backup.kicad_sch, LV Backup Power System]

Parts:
BT1: 18650; BatteryHolder_Keystone_1042_1x18650
C22, C25: 4.7u; C_0805_2012Metric
C23: 1u; C_0603_1608Metric_Pad1.08x0.95mm_HandSolder
C24: 100n; C_0603_1608Metric
C26, C27: 22u; C_1210_3225Metric
C29: 1u; C_0603_1608Metric
D5: PMEG2005; D_SOD-123F
L2: 4.7u; L_Coilcraft_XAL4040-XXX
R20, R22, R27, R28, R31, R33, R35: 0; R_0603_1608Metric; not fitted
R21, R23, R26, R29, R30, R32, R34: 0; R_0603_1608Metric
R24: 100k; R_0603_1608Metric
R25: 20k; R_0603_1608Metric
R36, R37: 1Meg; R_0603_1608Metric
U4: LTC3106; QFN-20-1EP_3x4mm_P0.5mm_EP1.65x2.65mm
U5: MCP6006; TSOT-23-5

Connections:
+5V: C22.1, R24.1, U4.16 (V_{IN}); also elsewhere on the board
/BACKUP_PG: U4.7 (PGOOD); also elsewhere on the board
/Backup/BKUP_BATT: BT1.1 (+), C23.1, R36.1, U4.14 (ENVSTR), U4.19 (V_{STORE}), U4.20 (V_{CAP})
/Backup/BKUP_BSEL: R28.2, R29.1, U4.11 (PRI)
/Backup/BKUP_ILIM: R26.2, R27.1, U4.12 (ILIMSEL)
/Backup/BKUP_LX1: L2.1, U4.18 (SW1)
/Backup/BKUP_LX2: D5.2 (A), L2.2, U4.17 (SW2)
/Backup/BKUP_MPP_SEL: R34.2, R35.1, U4.8 (MPP)
/Backup/BKUP_OS1: R30.2, R31.1, U4.5 (OS1)
/Backup/BKUP_OS2: R32.2, R33.1, U4.6 (OS2)
/Backup/BKUP_RUN: R24.2, R25.1, U4.13 (RUN)
/Backup/BKUP_SEL1: R20.2, R21.1, U4.10 (SS1)
/Backup/BKUP_SEL2: R22.2, R23.1, U4.9 (SS2)
/Backup/BKUP_VAUX: C25.1, D5.1 (K), U4.3 (V_{AUX})
/Backup/BKUP_VCC: C24.1, R20.1, R22.1, R26.1, R28.1, R30.1, R32.1, R34.1, U4.4 (V_{CC})
/CELL_SNS: U5.1, U5.4 (-); also elsewhere on the board
/VSUP: C26.1, C27.1, C29.1, U4.2 (V_{OUT}), U5.5 (V+); also elsewhere on the board
GND: BT1.2 (-), C22.2, C23.2, C24.2, C25.2, C26.2, C27.2, C29.2, R21.2, R23.2, R25.2, R27.2, R29.2, R31.2, R33.2, R35.2, R37.2, U4.15 (GND), U4.21 (GND), U5.2 (V-); also elsewhere on the board
unnamed: R36.2, R37.1, U5.3 (+)

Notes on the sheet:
VOUT Selection OS1 OS2 OUT ---------- Lo Lo 1.8V Lo Hi 2.2V Hi Lo 3.3V Hi Hi 5.0V
Hi : 650mA I_{IN}, 170mA I_{STORE} Lo : 100mA I_{IN}, 100mA I_{STORE}
Sheet Interfaces
Regulator Circuit
Pin Configuration Options
Cell Voltage Buffer
Hi : MPP Disabled R to GND : V_{MPP} = 1.5uA * R (Megohm)
Always on
OV/UV Settings (Rechargeable) SEL1 SEL2 OV UV ---------------------- Low Low 4.00 2.78 Low High 2.90 1.90 High Low 3.00 2.15 High High 4.00 3.00
Hi : Primary Batt Lo : Rechargeable

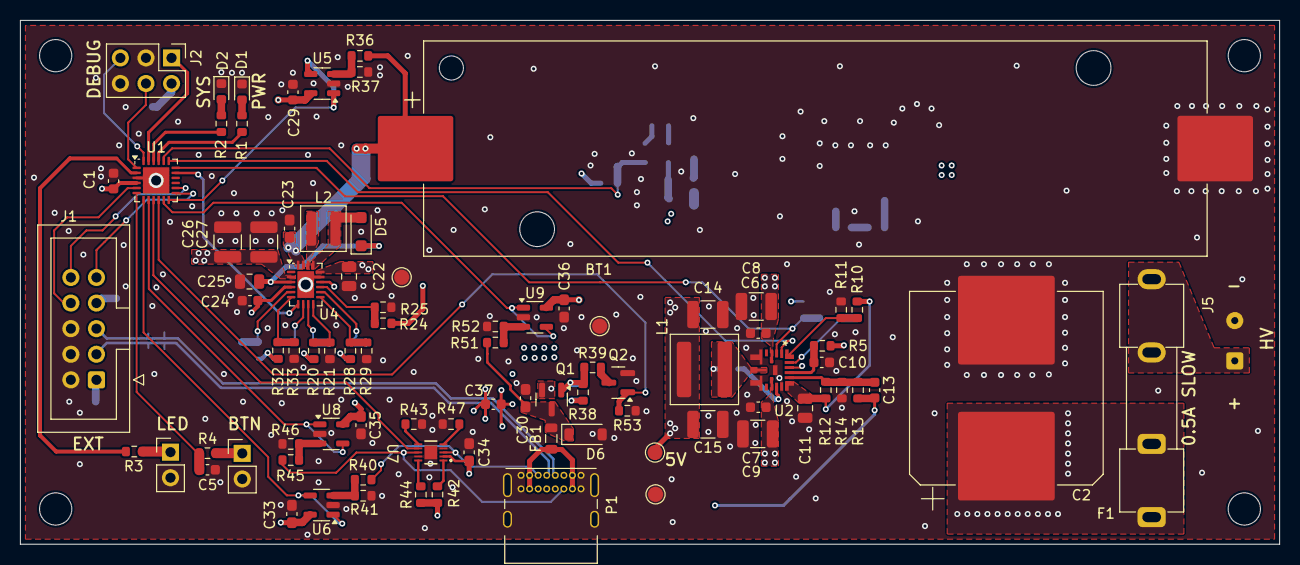
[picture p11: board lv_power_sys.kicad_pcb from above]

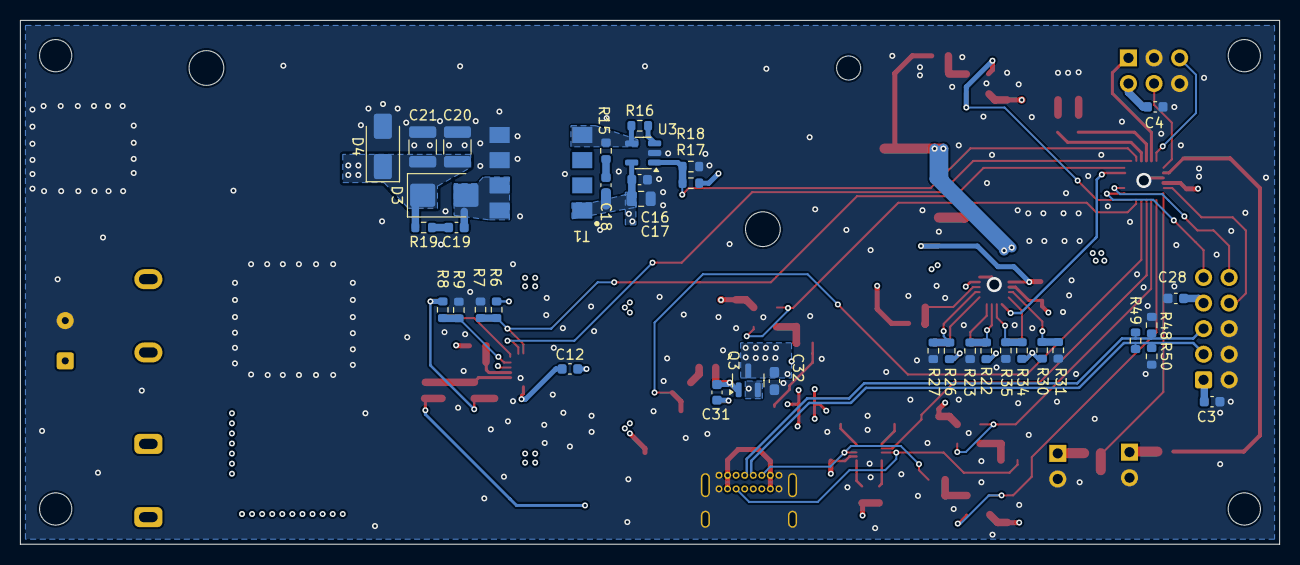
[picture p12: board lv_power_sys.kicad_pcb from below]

Board: 4 copper layers, 125.0 x 52.0 mm, 128 parts (37 on the bottom side), 71 nets.

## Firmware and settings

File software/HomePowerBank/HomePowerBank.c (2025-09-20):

#include <stdio.h>
#include "pico/stdlib.h"
#include "hardware/i2c.h"
#include "hardware/timer.h"
#include "hardware/watchdog.h"
#include "hardware/uart.h"


// I2C port definition
#define I2C_PORT i2c0
#define PIN_I2C_SDA 16
#define PIN_I2C_SCL 17

int64_t alarm_callback(alarm_id_t id, void *user_data) {
    // Put your timeout handler code in here
    return 0;
}


// debug uart port definition
#define DEBUG_UART uart0
#define DEBUG_BAUD_RATE 921000

#define DEBUG_TX_PIN 4
#define DEBUG_RX_PIN 5


int core0_loop()
{
    while (true)
    {




    }

    return 0;

}


int core1_loop()
{
    while (true)
    {

        // pet watchdog
        watchdog_update();

    }

    return 0;

}


int main()
{
    stdio_init_all();


    // I2C Initialization, 400kHz
    i2c_init(I2C_PORT, 400*1000);
    
    gpio_set_function(PIN_I2C_SDA, GPIO_FUNC_I2C);
    gpio_set_function(PIN_I2C_SCL, GPIO_FUNC_I2C);

    // uncomment two below if no external pullups
    // gpio_pull_up(PIN_I2C_SCL);
    // gpio_pull_up(PIN_I2C_SDA);

    // Get a free channel, panic() if there are none
    int chan = dma_claim_unused_channel(true);
    

    // Timer example code - This example fires off the callback after 2000ms
    add_alarm_in_ms(2000, alarm_callback, NULL, false);
    // For more examples of timer use see https://github.com/raspberrypi/pico-examples/tree/master/timer

    // Watchdog example code
    if (watchdog_caused_reboot()) {
        printf("Rebooted by Watchdog!\n");
        // Whatever action you may take if a watchdog caused a reboot
    }
    
    // Enable the watchdog, pause on debug
    watchdog_enable(100, 1);
    
    // You need to call this function at least more often than the 100ms in the enable call to prevent a reboot
    watchdog_update();

    // Set up our UART
    uart_init(DEBUG_UART, DEBUG_BAUD_RATE);

    gpio_set_function(DEBUG_RX_PIN, GPIO_FUNC_UART);
    gpio_set_function(DEBUG_TX_PIN, GPIO_FUNC_UART);
    
    // start up other core
    multicore_launch_core1(&core1_loop);

    // go to main task loop
    core0_loop();

}

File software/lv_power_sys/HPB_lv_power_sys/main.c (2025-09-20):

/*
 * HPB_lv_power_sys.c
 *
 * Created: 8/20/2025 10:01:49 PM
 * Author : Robert
 */


#include "HPB_lv_power_sys.h"

#define DBG_LEN 30
char dbg_line[DBG_LEN];


int main(void)
{

	state = BOOTUP;
	status = 0;

	int flags = 0;

	// reuse var for initializing string array
	for (flags = 0; flags < DBG_LEN; flags++) dbg_line[flags] = 0;
	flags = 0;

	// set up digital I/O
	SYS_LED_PORT.DIRSET = (1 << SYS_LED_PIN);
	SYS_LED_PORT.OUTSET = (1 << SYS_LED_PIN);

	PWR_LED_PORT.DIRSET = (1 << PWR_LED_PIN);
	PWR_LED_PORT.OUTCLR = (1 << PWR_LED_PIN);

	USR_LED_PORT.DIRSET = (1 << USR_LED_PIN);
	USR_LED_PORT.OUTCLR = (1 << USR_LED_PIN);

	USR_SW_PORT.DIRCLR = (1 << USR_SW_PIN);
	USR_SW_PORT.USR_SW_PINCTRL = PORT_PULLUPEN_bm;


	// cannot send info out debug port, but can watch variable when debugging
    flags = CLOCK_init();
	flags = USART_init();

	sei();		// enable interrupts (needed for USART transmission)

	// debug line
	sprintf(dbg_line,"\n\nInitializing...\n\0");
	flags = USART_transmit(dbg_line);

	CLOCK_delayMSec(2);

	// init ADC, send debug message
	flags = ADC_init();
	if (flags) sprintf(dbg_line,"ADC - Done\n\0");
	else sprintf(dbg_line,"ADC - Error\n\0");
	flags = USART_transmit(dbg_line);

	CLOCK_delayMSec(2);

	// kick off first conversion
	flags = ADC_startSweep();
	if (flags)
	{
		sprintf(dbg_line,"\nERROR running ADC\n\0");
		flags = USART_transmit(dbg_line);
	}

	state = IDLE;
	SYS_LED_PORT.OUTCLR = (1 << SYS_LED_PIN);

    while (1)
    {

		// get button status


		switch (state)
		{
			case IDLE:

				break;

			case SRC:

				break;

			case SINK:

				break;

			case HV_T_CHG:

				break;

			case CHG_CELL:

				break;

			case FAULT:

				break;

		}


		// start ADC sweep, loop until ADC is done, then sleep until next RTC tick

		ADC_startSweep();

		flags = ADC_isDone();

		while (flags == 0) flags = ADC_isDone();


    }
}

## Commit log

2025-01-10 Update README.md
    added links to KiCAD and draw.io
2025-01-10 expanded HW readme
    added basic description and specs for internal power and trickle charge circuits
2025-01-11 added custom KiCAD symbols
    added some IC symbols to a KiCAD library for use in circuit design
2025-02-07 started uC program, created hw USB interface, created LV power backup
    started uC program (RP2040 using VSCode), added USB C port and toggles for CCx pin terminations and voltage signals/buffers, added LV power backup system (intended for microcontroller)
    [lv_backup.kicad_pcb, lv_backup.kicad_sch, mcu.kicad_pcb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]
2025-02-07 lv backup hw update, usb interface hw update, MCU pinout spreadsheet
    added spreadsheet for mapping / allocating MCU pins and resources
    updated LV backup schematic with divider / buffer amplifier for MCU measurement
    updated USB interface voltage buffers: all have high-impedance /2 buffers
    [RP2040_GPIO_chart.ods, lv_backup.kicad_sch, usb_interface.kicad_sch]
2025-02-07 hw amplifier change in lv backup and usb interface
    replaced AD8541 operational amplifier with MCP6006 (massive cost savings, on order of $1 per chip or more)
    [lv_backup.kicad_sch, usb_interface.kicad_sch]
2025-02-10 expanded mcu chart
    expanded spreadsheet of MCU resource assignment
    [RP2040_GPIO_chart.ods, RP2040_chart.ods, usb_interface.kicad_sch]
2025-02-15 library updates, mcu i2c devices
    added MAX31331 RTC to library, added EEPROM and RTC sub-schematic to MCU, expanded mcu planning chart
    [EEPROM-RTC.kicad_sch, RP2040_chart.ods, mcu.kicad_sch]
2025-03-08 I2C device notes
    added notes on I2C device addresses (in-schematic)
    [EEPROM-RTC.kicad_sch, mcu.kicad_sch]
2025-09-20 huge update
    massive update; finished lv power sys hardware design, started lv power sys mcu program
    [EEPROM-RTC.kicad_sch, MCU_Power.kicad_sch, RP2040_chart.ods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]
